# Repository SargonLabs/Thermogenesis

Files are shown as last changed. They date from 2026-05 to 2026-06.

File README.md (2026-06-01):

# Thermogenesis

Open-source hardware and software platform for non-contact thermal sensing of human presence in shared spaces.

A person touches a glass enclosure containing an infrared thermopile sensor. Body heat conducts through the glass wall and the sensor reads the temperature change. Capacitive touch detects contact instantly. The firmware fuses both signals, classifies the interaction by confidence level, and publishes it to a shared dataset via MQTT. Deployed across a network of institutions, the platform builds a civic record of human thermal presence without cameras, without identifiable data, and without proprietary infrastructure.

**Status:** Active R&D at [Sargon Labs](https://sargonlabs.com), Bethlehem, Pennsylvania.

## Prototype Demo

Working breadboard prototype: ESP32-S3, MLX90614 thermopile, capacitive touch through soda-lime glass, SK6812 RGBW LED thermal response, evidence_grade state machine.

**Video:** [Breadboard prototype demo](https://youtu.be/ObmN-5IK4TE)

### Breadboard Test Results (May 2026)

| Test | Delta | Response | Grade |
|---|---|---|---|
| Direct IR, no glass | 6.8°C | < 1 second | estimated |
| Through soda-lime glass, sustained contact | 0.96°C peak | ~10 seconds to threshold | measured |
| Thermal decay after hand removal | below 0.5°C | ~12-15 seconds | idle |

Glass is opaque at the thermopile's 5.5-14μm wavelength. The sensor reads conduction-driven surface temperature change, not transmitted IR. Any glass composition works.

Full test data: [docs/test-results_v01_prototype.md](docs/test-results_v01_prototype.md)

## Architecture

```
┌─────────────────────────────┐
│  Glass enclosure            │
│  ┌────────────────────────┐ │
│  │ ESP32-S3               │ │
│  │ MLX90614 thermopile    │ │
│  │ Capacitive touch (GPIO)│ │
│  │ SK6812 RGBW LEDs       │ │
│  │ USB-C PD power         │ │
│  └────────────────────────┘ │
└─────────────┬───────────────┘
              │ MQTT / TLS
              ▼
┌─────────────────────────────┐
│ MQTT broker (Mosquitto)     │
└─────────────┬───────────────┘
              │
              ▼
┌─────────────────────────────┐
│ PostgreSQL + TimescaleDB    │
│ Time-series thermal data    │
└─────────────┬───────────────┘
              │
              ▼
┌─────────────────────────────┐
│ REST API + web visualisation│
└─────────────────────────────┘
```

Each node operates independently with offline flash buffering. When connectivity is available, data flows to the shared backend. Every interaction is tagged with an `evidence_grade`:

- **measured** — capacitive touch detected AND thermopile delta ≥ 0.5°C confirmed within 10-second conduction window
- **estimated** — thermopile delta detected without touch confirmation
- **symbolic** — explicitly contributed via the REST API

The `evidence_grade` taxonomy is designed as a candidate vocabulary for the `resultQuality` field in the OGC SensorThings API. See the [evidence_grade specification](docs/evidence-grade-spec.md).

## Tech Stack

| Layer | Technology | Licence |
|---|---|---|
| PCB schematics & layout | KiCad | CERN-OHL-S-2.0 |
| Enclosure design | FreeCAD | CERN-OHL-S-2.0 |
| Firmware | ESP32 C++ / PlatformIO | GPL-3.0 |
| Backend | PostgreSQL, TimescaleDB, Mosquitto | AGPL-3.0 |
| Deployment | Docker Compose | AGPL-3.0 |
| Protocol & documentation | MQTT + JSON schema | CC-BY-SA-4.0 |

## Repository Structure

```
thermogenesis/
├── firmware/
│   ├── src/
│   │   └── main.cpp          # ESP32-S3 firmware (sensor fusion, LEDs, evidence_grade)
│   └── platformio.ini         # PlatformIO build configuration
├── hardware/
│   ├── LICENSE                # CERN-OHL-S-2.0
│   └── thermogenesis_schematic_v0.1.png  # Breadboard prototype schematic
├── docs/
│   ├── protocol.md            # MQTT topic structure and payload format
│   ├── evidence-grade-spec.md # evidence_grade specification with OGC SensorThings mapping
│   ├── test-results_v01_prototype.md  # Breadboard empirical data
│   └── Thermogenesis_Architecture.pdf # System architecture diagram
├── enclosure/                 # Glass mold profiles, mounting specs (FreeCAD) — future
├── backend/                   # MQTT broker config, DB schema, API — future
├── LICENSE                    # GPL-3.0 (firmware, default)
└── CONTRIBUTING.md
```

## Hardware

- **MCU:** ESP32-S3-WROOM-1 (dual-core 240MHz, Wi-Fi, BLE, native USB, capacitive touch)
- **IR sensor:** MLX90614ESF (5.5–14μm far-IR thermopile, I2C, ±0.5°C accuracy)
- **LEDs:** SK6812 RGBW (addressable, warm white channel)
- **Touch:** Capacitive sensing via ESP32-S3 native touch pins, coupled through glass wall with copper foil electrode
- **Power:** USB-C (3.3V from onboard LDO; 5V pin inactive on UART port)
- **PCB:** Stacked design, ~35mm diameter (target production form factor)

## How It Works

The MLX90614 thermopile reads the temperature of the inner glass surface. When a person touches the outside of the glass, body heat conducts through the wall and raises the inner surface temperature. The sensor detects this change. Capacitive touch sensing through the glass provides an immediate contact signal. The firmware fuses both inputs to classify each interaction.

The glass enclosure is not an IR-transparent window. Both borosilicate and soda-lime glass are opaque in the MLX90614's 5.5-14μm sensing band. The glass acts as a thermal intermediary: body heat conducts through the wall, the inner surface warms, and the thermopile reads the surface temperature change. This means the conduction approach works across glass compositions, though the signal quality varies with thickness and thermal conductivity.

Capacitive touch fires instantly. The thermal signal takes 3-15 seconds depending on glass thickness. The evidence_grade decision tree handles this asymmetry: touch triggers first, then the system waits up to 10 seconds for thermal confirmation.

## Documentation

- [MQTT Protocol Specification](docs/protocol.md)
- [evidence_grade Specification](docs/evidence-grade-spec.md) — confidence metadata for civic sensor observations, with OGC SensorThings mapping
- [Breadboard Test Results](docs/test-results_v01_prototype.md)
- [System Architecture (PDF)](docs/Thermogenesis_Architecture.pdf)
- [Breadboard Schematic](hardware/thermogenesis_schematic_v0.1.png)

## Contributing

See [CONTRIBUTING.md](CONTRIBUTING.md).

## Contact

William Janczewski — [Sargon Labs](https://sargonlabs.com), Bethlehem, PA

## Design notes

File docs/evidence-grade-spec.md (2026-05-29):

# evidence_grade — Confidence Metadata for Civic Sensor Observations

**Version:** 0.1.0 (draft)
**Licence:** CC-BY-SA-4.0
**Author:** William Janczewski / Sargon Labs

## Problem

Civic sensing platforms — Sensor.Community, Smart Citizen Kit, OpenEnergyMonitor — treat all sensor readings as equivalent. A calibrated reference instrument and a $5 consumer sensor produce observations that look identical in the database. There is no standard way to express how confident a platform is in a given reading, or what evidence supports it.

The OGC SensorThings API, the international standard for IoT sensor observations (OGC 15-078r6), defines a `resultQuality` field in its Observation entity. This field is intended to carry data quality metadata. In practice, it is almost universally empty — no standard vocabulary exists for what to put in it.

This document proposes `evidence_grade`: a typed, sensor-fusion-based confidence vocabulary for civic sensor observations.

## Specification

Each observation carries an `evidence_grade` field with one of three values:

| Grade | Definition | Evidence required |
|---|---|---|
| `measured` | High-confidence observation confirmed by multiple sensor inputs | Primary sensor reading above threshold AND secondary sensor confirmation within a defined time window |
| `estimated` | Medium-confidence observation from a single sensor input | Primary sensor reading above threshold, without secondary confirmation |
| `symbolic` | Explicit human or API contribution, not derived from sensor data | Deliberate entry via API or user interface |

## Design Principles

**Typed, not numeric.** Quality scores (0.0–1.0) are hard to interpret across different sensor types and deployments. A categorical grade with clear semantic meaning is more useful for downstream consumers and more honest about what the sensor system actually knows.

**Sensor-fusion-based.** The grade is determined by how many independent sensor inputs agree, not by a statistical model of sensor accuracy. This makes it applicable to any multi-sensor system, not just thermopile+capacitive sensing.

**Deployment-configurable.** The thresholds that determine grade boundaries are set per deployment, not hardcoded in the specification. A node in a warm environment has different baseline characteristics than one in a cool environment. The specification defines the grades and the decision logic; the deployment operator configures the thresholds.

**Separable from Thermogenesis.** The evidence_grade vocabulary is designed to be adopted by any civic sensing platform, regardless of what sensor type it uses. An air quality network could classify readings as `measured` (calibrated instrument with cross-reference), `estimated` (consumer sensor without calibration), or `symbolic` (user-reported observation). The vocabulary is not specific to thermal sensing.

## Reference Implementation: Thermogenesis

In Thermogenesis, evidence_grade is determined by fusing two independent sensor inputs:

**Primary sensor:** MLX90614 infrared thermopile, measuring inner glass surface temperature. The primary signal is `delta_c` — the difference between the object temperature and the ambient temperature.

**Secondary sensor:** ESP32-S3 native capacitive touch, detecting physical contact through the glass wall.

### Decision tree

```
                     ┌──────────────────────┐
                     │  delta_c >= threshold? │
                     └──────────┬───────────┘
                           ┌────┴────┐
                           │ NO      │ YES
                           ▼         ▼
                        ┌─────┐   ┌──────────────────────┐
                        │IDLE │   │ touch confirmed       │
                        └─────┘   │ within confirm_window?│
                                  └──────────┬───────────┘
                                        ┌────┴────┐
                                        │ NO      │ YES
                                        ▼         ▼
                                  ┌───────────┐ ┌──────────┐
                                  │ ESTIMATED │ │ MEASURED  │
                                  └───────────┘ └──────────┘
```

### Configurable parameters

| Parameter | Default | Description |
|---|---|---|
| `threshold` | 0.5 °C | Minimum delta_c to trigger grade assignment |
| `confirm_window_ms` | 10000 | Maximum time between capacitive touch and thermopile confirmation |
| `hysteresis_c` | 0.2 °C | Delta must drop below `threshold - hysteresis` before a new event triggers |

### Empirical results (breadboard prototype, May 2026)

| Test condition | delta_c | Response time | Touch signal | Grade |
|---|---|---|---|---|
| Direct IR, no glass, palm at 5cm | 6.8 °C | < 1 second | n/a | estimated |
| Through soda-lime glass (light fixture dome), sustained contact | 0.96 °C peak | ~10 seconds to threshold | 30,000 (baseline 23,000) | measured |
| Through soda-lime glass, hand removed | Decay from 0.7 to below 0.5 °C | ~12-15 seconds | Returns to baseline immediately | estimated → idle |

Glass composition: soda-lime (standard light fixture). Wall thickness: approximately 2-3mm. Ambient temperature: 24.5°C.

## Payload format

```json
{
  "ts": "2026-05-28T20:15:01.000Z",
  "grade": "measured",
  "delta_c": 0.96,
  "ambient_c": 24.5,
  "object_c": 25.4,
  "touch_raw": 30376,
  "confirm_delay_ms": 8200,
  "firmware_version": "0.1.0"
}
```

## Mapping to OGC SensorThings API

The evidence_grade field maps directly to the `resultQuality` property of the `Observation` entity in OGC SensorThings API (OGC 15-078r6, Section 8.2.3). The SensorThings specification defines `resultQuality` as type `DQ_Element` (from ISO 19157), which is broadly structured but rarely populated in practice.

A minimal SensorThings-compatible encoding:

```json
{
  "resultQuality": {
    "nameOfMeasure": "evidence_grade",
    "value": "measured",
    "description": "Thermopile delta >= threshold AND capacitive touch confirmed within confirmation window"
  }
}
```

This allows any SensorThings-compatible server to store and query evidence_grade metadata alongside standard observation data, without requiring changes to the SensorThings data model.

## Adoption path

The evidence_grade vocabulary is released under CC-BY-SA-4.0. Any civic sensing platform can adopt it by:

1. Adding an `evidence_grade` field to their observation payload
2. Defining which of their sensor inputs constitute primary evidence (for the measured/estimated distinction)
3. Configuring thresholds per deployment
4. Optionally mapping to the OGC SensorThings `resultQuality` field for standards compatibility

The vocabulary is intentionally minimal — three grades, clear semantics, no required infrastructure beyond a string field in the observation payload.

## References

- OGC SensorThings API Part 1: Sensing, Version 1.1 (OGC 18-088)
- OGC Observations and Measurements (ISO 19156:2011)
- ISO 19157: Geographic information — Data quality
- Sensor.Community (sensor.community)
- Smart Citizen Kit (smartcitizen.me)
- Thermogenesis project repository (github.com/SargonLabs/Thermogenesis)

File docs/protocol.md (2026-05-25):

# Thermogenesis MQTT Protocol Specification

**Version:** 0.1.0 (draft)
**Licence:** CC-BY-SA-4.0

## Topic structure

```
thermogenesis/{site_id}/{node_id}/{message_type}
```

- `site_id` — unique identifier for the deployment site (e.g. `broughal-ms`)
- `node_id` — unique identifier for the node at that site (e.g. `node-001`)
- `message_type` — one of: `event`, `heartbeat`, `status`

### Examples

```
thermogenesis/broughal-ms/node-001/event
thermogenesis/broughal-ms/node-001/heartbeat
thermogenesis/broughal-ms/node-001/status
```

## Message types

### event

Published on state change: touch begin, touch end, or evidence_grade transition.

```json
{
  "ts": "2026-05-27T14:32:01.000Z",
  "type": "touch_begin",
  "grade": "measured",
  "delta_c": 1.4,
  "ambient_c": 22.1,
  "object_c": 23.5,
  "touch_raw": 72000,
  "firmware_version": "0.1.0"
}
```

| Field | Type | Description |
|---|---|---|
| `ts` | ISO 8601 string | Timestamp (UTC) |
| `type` | string | `touch_begin`, `touch_end`, `proximity_begin`, `proximity_end` |
| `grade` | string | `measured`, `estimated`, `symbolic` |
| `delta_c` | float | Object temperature minus ambient temperature (°C) |
| `ambient_c` | float | MLX90614 ambient (die) temperature (°C) |
| `object_c` | float | MLX90614 object (glass surface) temperature (°C) |
| `touch_raw` | integer | Raw capacitive touch sensor value |
| `firmware_version` | string | Semver firmware version |

### heartbeat

Published every 60 seconds during sustained contact. Same schema as `event`, with `type: "heartbeat"`.

### status

Published on boot, on network reconnect, and every 5 minutes when idle.

```json
{
  "ts": "2026-05-27T14:30:00.000Z",
  "type": "boot",
  "firmware_version": "0.1.0",
  "uptime_s": 0,
  "wifi_rssi": -42,
  "flash_buffered_events": 0,
  "free_heap_bytes": 245760
}
```

## evidence_grade classification

| Grade | Condition | Meaning |
|---|---|---|
| `measured` | `delta_c >= threshold` AND capacitive touch confirmed within confirmation window | Direct human contact detected by both sensors |
| `estimated` | `delta_c >= threshold` without capacitive touch | Thermal presence detected nearby (body heat without touch) |
| `symbolic` | Submitted via REST API | Deliberate non-sensor contribution |

### Parameters (configurable per deployment)

| Parameter | Default | Description |
|---|---|---|
| `threshold` | 0.5 °C | Minimum temperature delta to trigger classification |
| `confirmation_window_ms` | 10000 | Max time between capacitive touch and thermopile confirmation |
| `hysteresis_c` | 0.2 °C | Delta must drop below `threshold - hysteresis` before a new event triggers |
| `heartbeat_interval_ms` | 60000 | Interval between heartbeat messages during sustained contact |

## Transport

- **Protocol:** MQTT v3.1.1 over TLS (port 8883)
- **QoS:** 1 (at least once delivery)
- **Offline buffering:** Events buffered to ESP32 flash ring buffer during connectivity loss, published in order on reconnect
- **Broker:** Mosquitto (reference deployment)

## Data types

All timestamps are ISO 8601 UTC. All temperatures are Celsius. All payloads are JSON (UTF-8).

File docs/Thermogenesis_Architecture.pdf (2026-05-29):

# Thermogenesis

### System Architecture — Rev 0.1, May 2026

### Sargon Labs

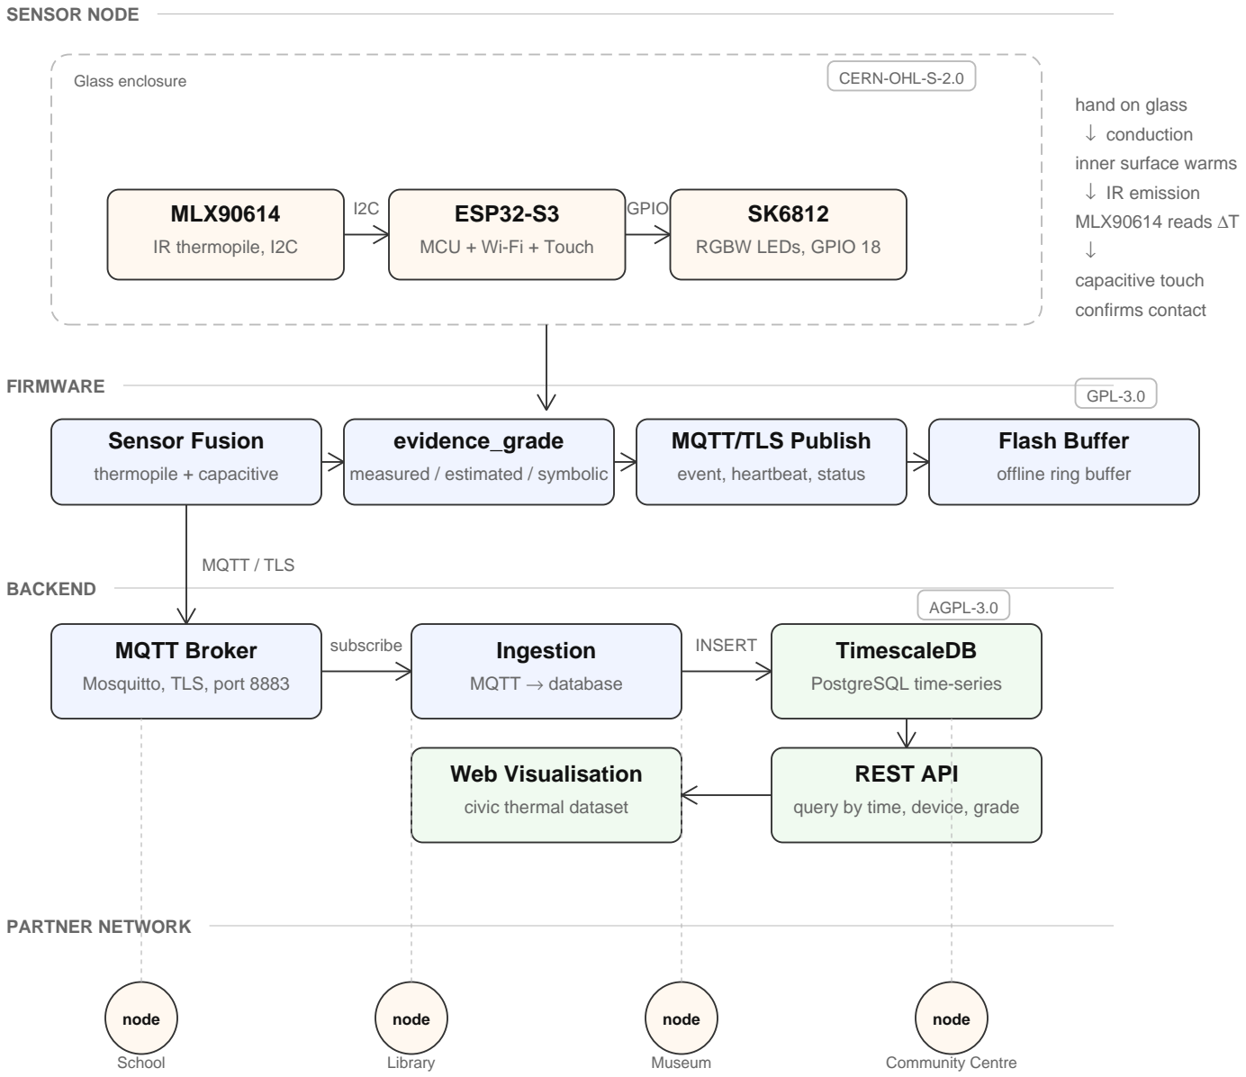
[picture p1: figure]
SENSOR NODE; Glass enclosure; MLX90614; IR thermopile, I2C; ESP32-S3; MCU + Wi-Fi + Touch; RGBW LEDs, GPIO 18; CERN-OHL-S-2.0; GPIO; hand on glass ↓ conduction inner surface warms ↓ IR emission MLX90614 reads ∆T ↓ capacitive touch confirms contact; FIRMWARE; Sensor Fusion; thermopile + capacitive; evidence_grade; measured / estimated / symbolic; MQTT/TLS Publish; event, heartbeat, status; Flash Buffer; offline ring buffer; GPL-3.0; BACKEND; MQTT Broker; Mosquitto, TLS, port 8883; Ingestion; MQTT → database; TimescaleDB; PostgreSQL time-series; subscribe; INSERT; AGPL-3.0; MQTT / TLS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

Each node connects independently. Any institution can build, deploy, and join the shared network.

github.com/SargonLabs/Thermogenesis Hardware: CERN-OHL-S-2.0 · Firmware: GPL-3.0 · Backend: AGPL-3.0 · Docs: CC-BY-SA-4.0 William Janczewski — Sargon Labs

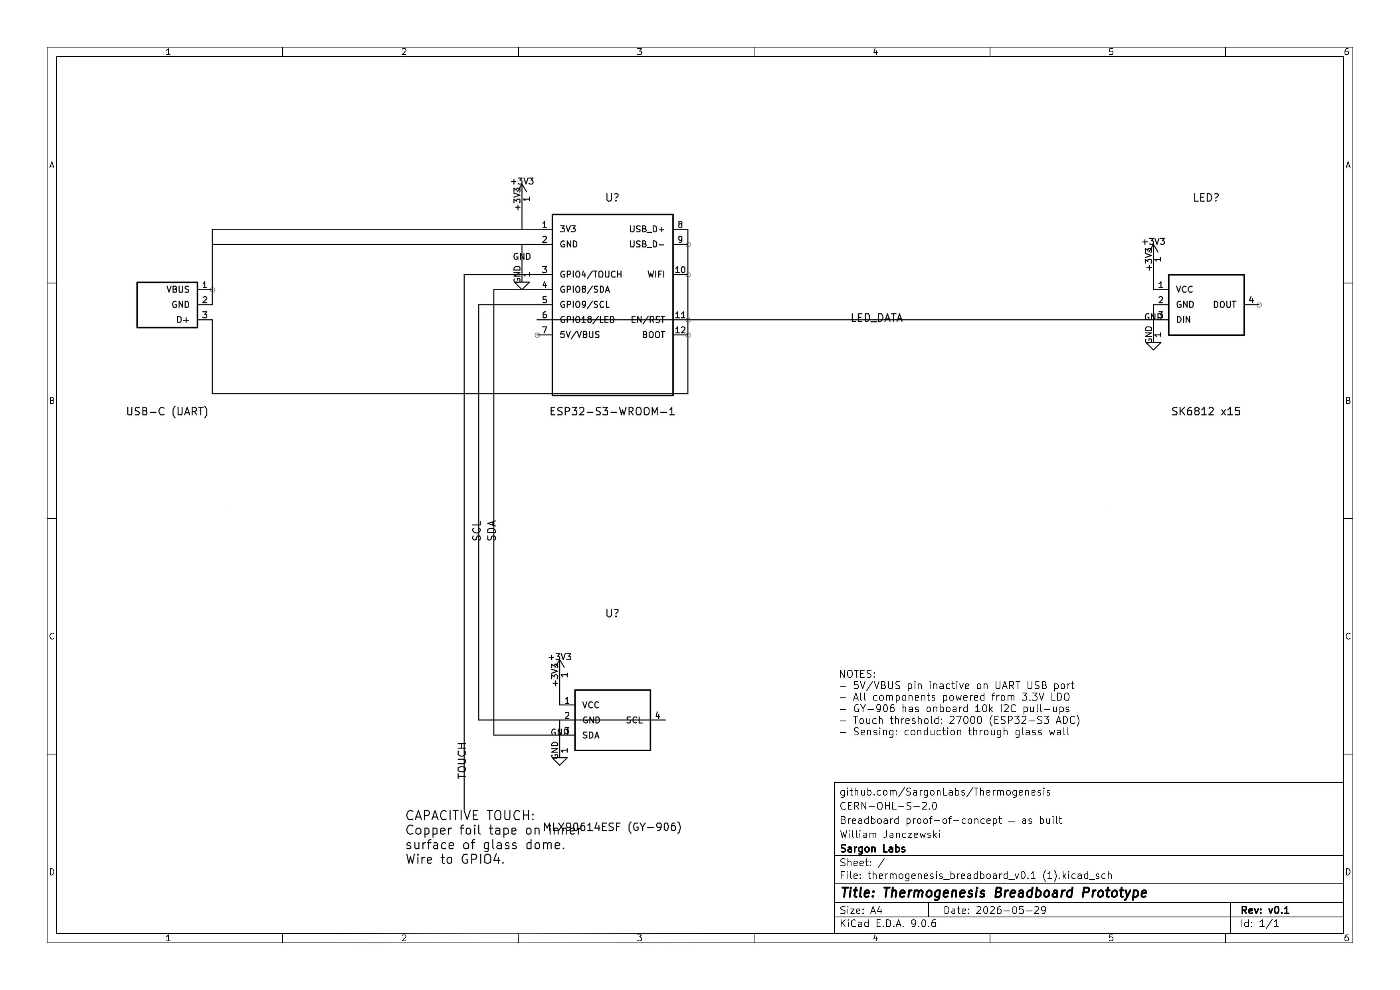
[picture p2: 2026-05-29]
hardware/ThermoG_breadboard_prototype_schematic_v01.png

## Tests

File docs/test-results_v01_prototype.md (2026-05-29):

# Breadboard Prototype Test Results

**Date:** May 28, 2026
**Location:** Sargon Labs, Bethlehem, PA
**Hardware:** ESP32-S3-WROOM-1 (N16R8), MLX90614ESF (GY-906 breakout), SK6812 RGBW LEDs, capacitive touch via copper foil on glass
**Glass:** Soda-lime globe (light fixture dome), estimated wall thickness 2-3mm
**Ambient temperature:** 24.4–24.8°C
**Firmware:** Thermogenesis Phase 2 (see firmware/src/main.cpp)

## Test A — Direct IR (no glass)

Palm flat, 5cm above sensor.

| Metric | Value |
|---|---|
| Ambient | 24.5°C |
| Object (peak) | 31.3°C |
| Delta (peak) | 6.8°C |
| Response time | < 1 second |
| State | ESTIMATED (no touch sensor in path) |

## Test B — Through soda-lime glass, sustained contact

Palm pressed flat against outside of glass dome, copper tape electrode on inside surface, MLX90614 positioned inside dome pointing at glass wall.

| Metric | Value |
|---|---|
| Ambient | 24.5–24.8°C |
| Object (peak) | 25.5°C |
| Delta (peak) | 0.96°C |
| Time to 0.5°C threshold | ~8–10 seconds |
| Time to peak | ~120 seconds (2 minutes) |
| Capacitive touch baseline | ~23,000 |
| Capacitive touch (through glass) | ~29,000–30,400 |
| Touch threshold used | 27,000 |
| State | MEASURED (touch + thermal confirmed) |

## Test C — Thermal decay after hand removal

Hand removed after sustained contact.

| Time after removal | Delta | State |
|---|---|---|
| 0 seconds | 0.76°C | ESTIMATED |
| 3 seconds | 0.68°C | ESTIMATED |
| 6 seconds | 0.60°C | ESTIMATED |
| 9 seconds | 0.54°C | ESTIMATED |
| 12 seconds | 0.46°C | IDLE |
| 15 seconds | 0.38°C | IDLE |

Decay from above-threshold to below-threshold: approximately 12-15 seconds.

## Observations

1. **Conduction-based sensing confirmed.** The glass is opaque to the MLX90614's 5.5–14μm sensing band. The sensor reads inner glass surface temperature, which rises through thermal conduction from body contact on the outside. This means any glass composition works.

2. **Capacitive touch through glass confirmed.** Signal attenuated from 350,000+ (direct contact with bare wire) to ~30,000 (through 2-3mm soda-lime glass). Still well above a detectable threshold.

3. **Two-signal timing asymmetry confirmed.** Capacitive touch triggers within milliseconds. Thermal delta takes 8–10 seconds to cross the 0.5°C threshold. The evidence_grade decision tree correctly handles this: touch fires first (PENDING), thermal confirms later (MEASURED).

4. **Thermal persistence after release.** The glass retains heat for 12–15 seconds after hand removal. During this period, the system correctly transitions from MEASURED to ESTIMATED (thermal without touch) to IDLE.

5. **Touch signal instability near threshold.** Capacitive values through glass fluctuate between 26,000 and 30,400 during sustained contact, occasionally dropping below the 27,000 threshold. This causes brief MEASURED → ESTIMATED → MEASURED transitions during a single sustained touch. Production firmware should add hysteresis or a debounce timer to the touch classification.

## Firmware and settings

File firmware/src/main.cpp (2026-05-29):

/*
 * Thermogenesis v0.1.0 — Breadboard Prototype Firmware
 * https://github.com/SargonLabs/Thermogenesis
 *
 * ESP32-S3 + MLX90614 thermopile + capacitive touch + SK6812 RGBW LEDs
 * Conduction-based thermal sensing through glass enclosure
 * evidence_grade classification: measured / estimated / symbolic
 *
 * Licence: GPL-3.0
 * Author: William Janczewski / Sargon Labs
 */

#include <Arduino.h>
#include <Wire.h>
#include <Adafruit_MLX90614.h>
#include <Adafruit_NeoPixel.h>

#define PIN_SDA       8
#define PIN_SCL       9
#define PIN_TOUCH     4
#define PIN_LED_DATA  18
#define LED_COUNT     15
#define TOUCH_THRESHOLD 27000
#define TEMP_THRESHOLD 0.5

Adafruit_MLX90614 mlx = Adafruit_MLX90614();
Adafruit_NeoPixel leds(LED_COUNT, PIN_LED_DATA, NEO_GRBW + NEO_KHZ800);

float ledWarmth[LED_COUNT];
float targetWarmth = 0.0;
unsigned long lastUpdate = 0;

void setup() {
  Serial.begin(9600);
  delay(1000);
  Serial.println("--- Thermogenesis v0.1.0 ---");

  Wire.setPins(PIN_SDA, PIN_SCL);

  if (!mlx.begin()) {
    Serial.println("ERROR: MLX90614 not found. Check wiring.");
    while (1) delay(1000);
  }
  Serial.println("MLX90614 connected.");

  leds.begin();
  leds.setBrightness(50);

  for (int i = 0; i < LED_COUNT; i++) {
    ledWarmth[i] = 0.0;
  }

  Serial.println("Ready.");
  Serial.println();
}

void setLedFromWarmth(int i, float w, float pulse) {
  uint8_t r, g, b, wh;

  if (w < 0.05) {
    float brightness = 0.2 + 0.12 * pulse;
    r = 0;
    g = 0;
    b = (uint8_t)(70 * brightness);
    wh = 0;
  } else if (w < 0.25) {
    float t = (w - 0.05) / 0.2;
    float brightness = 0.4 + 0.1 * pulse;
    r = (uint8_t)(20 * t * brightness);
    g = 0;
    b = (uint8_t)((70 + 30 * t) * brightness);
    wh = 0;
  } else if (w < 0.5) {
    float t = (w - 0.25) / 0.25;
    r = (uint8_t)(20 + 150 * t);
    g = (uint8_t)(40 * t);
    b = (uint8_t)(100 * (1.0 - t));
    wh = (uint8_t)(30 * t);
  } else if (w < 0.75) {
    float t = (w - 0.5) / 0.25;
    r = (uint8_t)(170 + 50 * t);
    g = (uint8_t)(40 + 20 * t);
    b = 0;
    wh = (uint8_t)(30 + 40 * t);
  } else {
    float brightness = 0.8 + 0.2 * pulse;
    r = (uint8_t)(230 * brightness);
    g = (uint8_t)(70 * brightness);
    b = 0;
    wh = (uint8_t)(80 * brightness);
  }

  leds.setPixelColor(i, leds.Color(r, g, b, wh));
}

void loop() {
  float ambient = mlx.readAmbientTempC();
  float object  = mlx.readObjectTempC();
  float delta   = object - ambient;
  int   touchRaw = touchRead(PIN_TOUCH);
  bool  touched  = (touchRaw > TOUCH_THRESHOLD);

  if (delta < 0.1) {
    targetWarmth = 0.0;
  } else if (delta < 2.5) {
    targetWarmth = delta / 2.5;
  } else {
    targetWarmth = 1.0;
  }

  float time = millis() / 1000.0;

  for (int i = 0; i < LED_COUNT; i++) {
    float offset = (float)i / (float)LED_COUNT;

    float delay_factor = offset * 0.4;
    float localTarget = targetWarmth - delay_factor;
    if (localTarget < 0) localTarget = 0;
    if (localTarget > 1) localTarget = 1;

    if (localTarget > ledWarmth[i]) {
      ledWarmth[i] += 0.015 + 0.008 * (1.0 - offset);
      if (ledWarmth[i] > localTarget) ledWarmth[i] = localTarget;
    } else {
      ledWarmth[i] -= 0.06;
      if (ledWarmth[i] < localTarget) ledWarmth[i] = localTarget;
      if (ledWarmth[i] < 0) ledWarmth[i] = 0;
    }

    float localPulse = sin(time * 0.8 + i * 0.5) * 0.5 + 0.5;

    setLedFromWarmth(i, ledWarmth[i], localPulse);
  }

  leds.show();

  if (millis() - lastUpdate >= 1000) {
    lastUpdate = millis();

    Serial.print(ambient, 1);
    Serial.print("C    ");
    Serial.print(object, 1);
    Serial.print("C    ");
    Serial.print(delta, 2);
    Serial.print("C    ");
    Serial.print(touchRaw);
    Serial.print("  [");
    Serial.print(touched ? "TOUCH" : "-----");
    Serial.print("]  ");

    if (touched && delta >= TEMP_THRESHOLD) {
      Serial.println("MEASURED");
    } else if (touched) {
      Serial.println("PENDING");
    } else if (delta >= TEMP_THRESHOLD) {
      Serial.println("ESTIMATED");
    } else {
      Serial.println("IDLE");
    }
  }

  delay(30);
}

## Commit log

2026-05-29 Organize repository structure.
    [ThermoG_breadboard_v0.1 (1).kicad_sch]
2026-06-01 Schematic updated, README updated
    [ThermoG_breadboard_v0.1.kicad_sch]
